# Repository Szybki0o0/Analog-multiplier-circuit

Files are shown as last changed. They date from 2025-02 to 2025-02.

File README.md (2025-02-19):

# Analog Multiplier circuit

## Overview
The multiplier circuit presented in the schematic is an electronic system composed of several functional blocks working together to perform mathematical operations on input signals.

mult

## Main Functional Blocks
The schematic consists of the following key sections:

1. **Power Supply (V+ and V-)**  
   - Voltage stabilization for the circuit.
   - Uses **MIC5207** for V+ regulation and **LT1054** as a charge pump for V-.

2. **Charge Pump**  
   - Responsible for generating the negative voltage required for some components.  
   - Utilizes **MCP6002** as an operational amplifier.
   - Utilizes **ADG779** as a CMOS switch.

3. **Voltage-Frequency Converter (VCF)**  
   - Based on **LM331N** operational amplifier, responsible for controlling the input signal through filtering.  
   - Includes adjustment via **RV1** potentiometer.

4. **Adding Offset**  
   - Allows adding a frequency shift to the input signal to allow correct operation with 0V.  
   - Implemented using **MCP6002**.

5. **Subtracting Offset**  
   - Compensates voltage by subtracting an offset value.  
   - Uses **MCP6002** and **RV2** potentiometer.

## How It Works
The circuit receives an input signal, which can be filtered and modified by adding or subtracting an offset. The processed signal is then transmitted to other circuit blocks where it can be used for further operations.

## Problems
VCF isn't working properly due to wrong choice of resistors and not enough current is flowing into integrated circuit.

## PCB
Physical implementation of a circuit:



## Author
Jakub Konior
Jakub Wiącek
Arkadiusz Kowalczyk

## Design Software
Designed using **KiCad EDA 8.0.2**.

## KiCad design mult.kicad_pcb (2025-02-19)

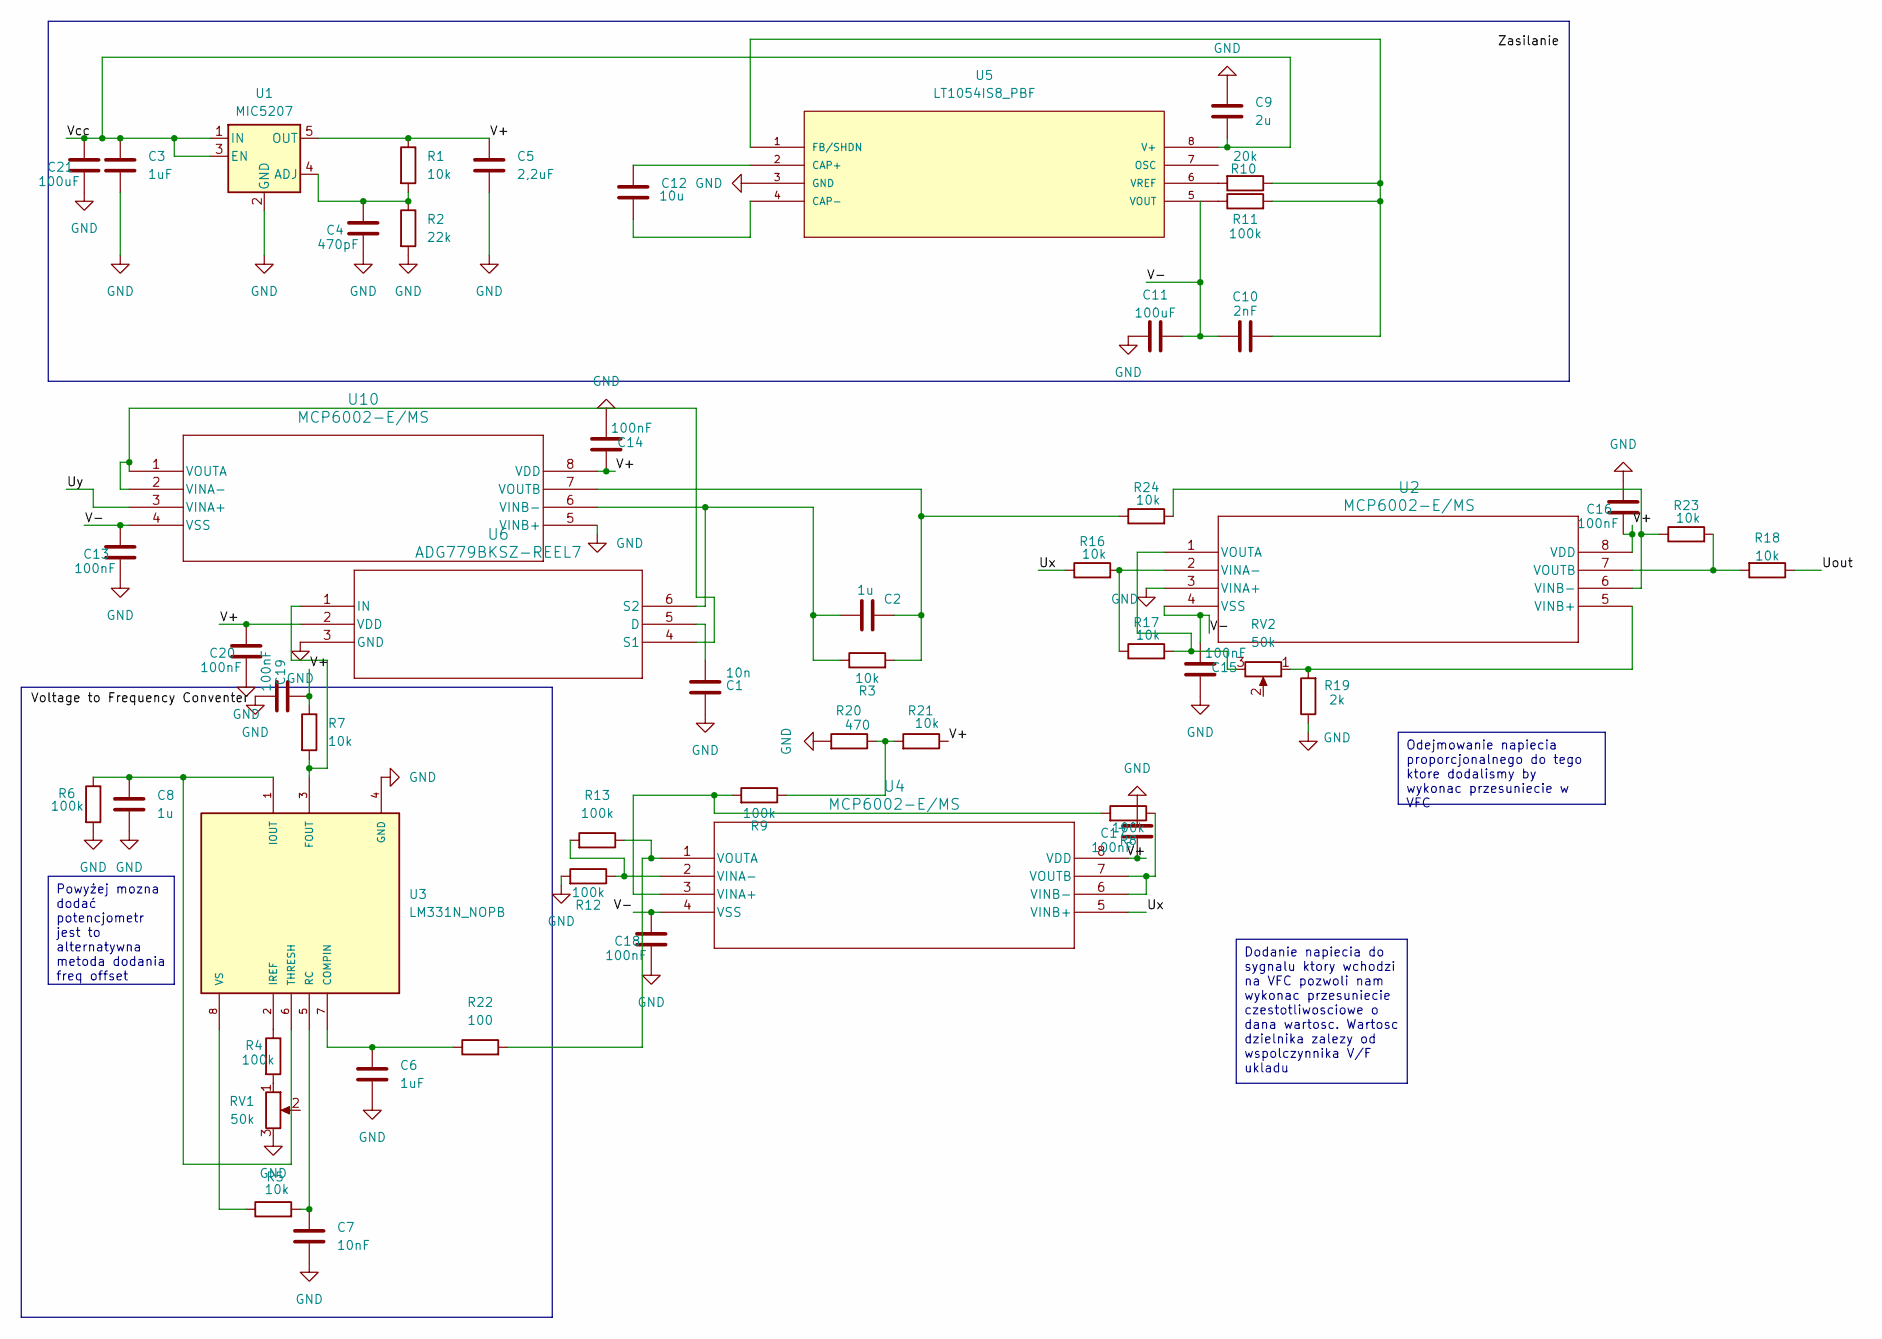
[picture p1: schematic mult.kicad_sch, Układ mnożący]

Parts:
C1: 10n; C_0805_2012Metric_Pad1.18x1.45mm_HandSolder
C2, C8: 1u; C_0805_2012Metric_Pad1.18x1.45mm_HandSolder
C3, C6: 1uF; C_0805_2012Metric_Pad1.18x1.45mm_HandSolder
C4: 470pF; C_0805_2012Metric_Pad1.18x1.45mm_HandSolder
C5: 2,2uF; C_0805_2012Metric_Pad1.18x1.45mm_HandSolder
C7: 10nF; CAP_B32529_02.5X06.5X07.3_TDK
C9: 2u; C_0805_2012Metric_Pad1.18x1.45mm_HandSolder
C10: 2nF; C_0805_2012Metric_Pad1.18x1.45mm_HandSolder
C11: 100uF; C_0805_2012Metric_Pad1.18x1.45mm_HandSolder
C12: 10u; C_0805_2012Metric_Pad1.18x1.45mm_HandSolder
C13, C14, C15, C16, C17, C18, C19, C20: 100nF; C_0805_2012Metric_Pad1.18x1.45mm_HandSolder
C21: 100uF; CP_EIA-3528-21_Kemet-B_Pad1.50x2.35mm_HandSolder
R1, R3, R5, R7, R16, R17, R18, R21, R23, R24: 10k; R_0805_2012Metric_Pad1.20x1.40mm_HandSolder
R2: 22k; R_0805_2012Metric_Pad1.20x1.40mm_HandSolder
R4, R6, R8, R9, R11, R12, R13: 100k; R_0805_2012Metric_Pad1.20x1.40mm_HandSolder
R10: 20k; R_0805_2012Metric_Pad1.20x1.40mm_HandSolder
R19: 2k; R_0805_2012Metric_Pad1.20x1.40mm_HandSolder
R20: 470; R_0805_2012Metric_Pad1.20x1.40mm_HandSolder
R22: 100; R_0805_2012Metric_Pad1.20x1.40mm_HandSolder
RV1, RV2: 50k; POT_3214W
U1: MIC5207; SOT-23-5
U2, U4, U10: MCP6002-E/MS; MSOP8_MC_MCH-L
U3: LM331N_NOPB; N08E_TEX; PARTREV 4040082/E 04/2010
U5: LT1054IS8_PBF; SO-8_S_LIT-L; MANUFACTURER_PART_NUMBER lt1054is8
U6: ADG779BKSZ-REEL7; KS_6_ADI-L

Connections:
/Uout: R18.1
/Ux: R16.1, U4.5 (VINB+)
/Uy: U10.3 (VINA+)
/V+: C5.1, C14.1, C16.2, C17.2, C19.1, C20.1, R1.1, R7.1, R21.1, U1.5 (OUT), U2.8 (VDD), U4.8 (VDD), U6.2 (VDD), U10.8 (VDD)
/V-: C10.1, C11.2, C13.1, C15.2, C18.1, U2.4 (VSS), U4.4 (VSS), U10.4 (VSS)
/Vcc: C3.1, C9.2, C21.1, U1.1 (IN), U1.3 (EN), U5.8 (V+)
GND: C1.2, C3.2, C4.2, C5.2, C6.2, C7.2, C8.2, C9.1, C11.1, C13.2, C14.2, C15.1, C16.1, C17.1, C18.2, C19.2, C20.2, C21.2, R2.2, R6.2, R12.2, R19.1, R20.2, RV1.3, U1.2 (GND), U2.3 (VINA+), U3.4 (GND), U5.3 (GND), U6.3 (GND), U10.5 (VINB+)
unnamed: R4.2, RV1.1
unnamed: R9.1, R20.1, R21.2
unnamed: C4.1, R1.2, R2.1, U1.4 (ADJ)
unnamed: R16.2, R17.1, U2.2 (VINA-)
unnamed 11: R19.2, RV2.1, U2.5 (VINB+); also elsewhere on the board
unnamed: R23.1, R24.2, U2.6 (VINB-)
unnamed 13: R17.2, RV2.3, U2.1 (VOUTA); also elsewhere on the board
unnamed: R18.2, R23.2, U2.7 (VOUTB)
unnamed: C6.1, R22.1, U3.7 (COMPIN)
unnamed: R7.2, U3.3 (FOUT), U6.1 (IN)
unnamed: C8.1, R6.1, U3.1 (IOUT), U3.6 (THRESH)
unnamed: R4.1, U3.2 (IREF)
unnamed: C7.1, R5.2, U3.5 (RC)
unnamed: R5.1, U3.8 (VS)
unnamed: R8.2, R9.2, U4.3 (VINA+)
unnamed: R12.1, R13.2, U4.2 (VINA-)
unnamed: R8.1, U4.6 (VINB-), U4.7 (VOUTB)
unnamed: R13.1, R22.2, U4.1 (VOUTA)
unnamed: C12.1, U5.2 (CAP+)
unnamed: C12.2, U5.4 (CAP-)
unnamed: C10.2, R10.1, R11.2, U5.1 (FB/SHDN)
unnamed: R11.1, U5.5 (VOUT)
unnamed: R10.2, U5.6 (VREF)
unnamed: C1.1, U6.5 (D)
unnamed: U6.4 (S1), U10.1 (VOUTA), U10.2 (VINA-)
unnamed: C2.1, R3.1, U6.6 (S2), U10.6 (VINB-)
unnamed: C2.2, R3.2, R24.1, U10.7 (VOUTB)

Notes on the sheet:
Dodanie napiecia do sygnalu ktory wchodzi na VFC pozwoli nam wykonac przesuniecie czestotliwosciowe o dana wartosc. Wartosc dzielnika zalezy od wspolczynnika V/F ukladu
Odejmowanie napiecia proporcjonalnego do tego ktore dodalismy by wykonac przesuniecie w VFC
Powyżej mozna dodać potencjometr jest to alternatywna metoda dodania freq offset

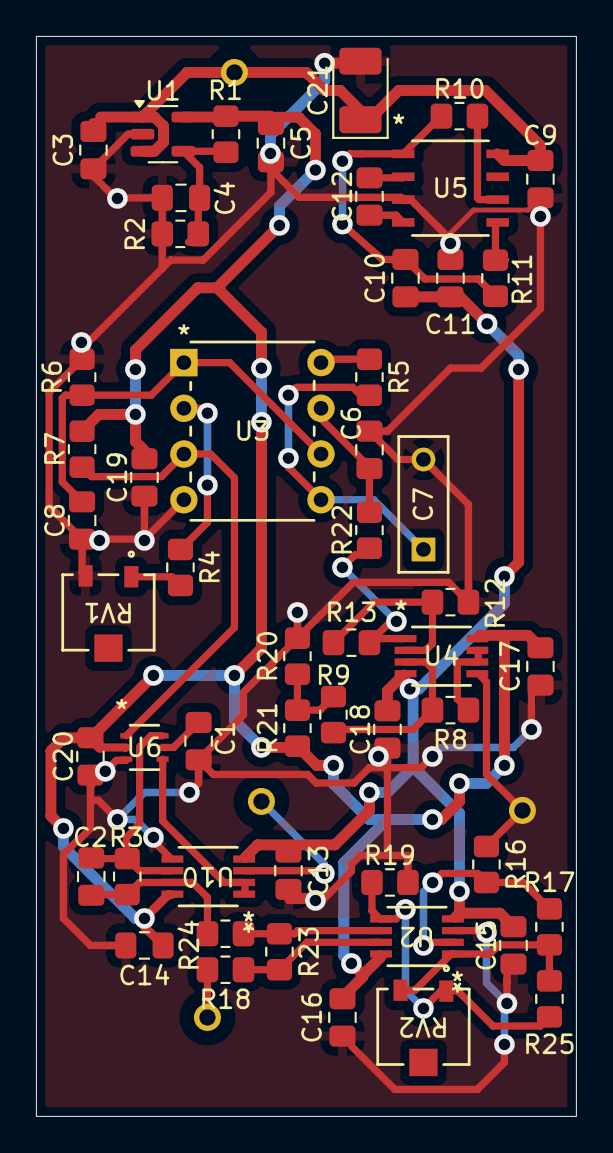
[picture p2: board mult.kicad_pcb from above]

Board: 2 copper layers, 30.0 x 60.0 mm, 53 parts (0 on the bottom side), 32 nets.

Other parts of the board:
R25: 10k; R_0805_2012Metric_Pad1.20x1.40mm_HandSolder

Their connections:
unnamed 11: R25.2; also elsewhere on the board
unnamed 13: R25.1; also elsewhere on the board
